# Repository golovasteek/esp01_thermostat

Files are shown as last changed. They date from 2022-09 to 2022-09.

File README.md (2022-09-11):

# Smart Thermostat based on ESP-01 board

ESP-01 Relay module

The software to run on the thermostat to control temperature in the
room with a floor heating.

The target board is ESP-01, but it should be possible to run it on
any ESP8266 board.

The project uses DS18b20 as temperature sensors

GPIO 2 is used to connect with senosor
GPIO 0 is used to control relay, relay is supposed to be active low.

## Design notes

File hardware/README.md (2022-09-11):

# Hardware design of the thermostat

## Tools

The hardware design is made in KiCAD version 5

You can view it on [CADLAB.io](https://cadlab.io/project/25945).

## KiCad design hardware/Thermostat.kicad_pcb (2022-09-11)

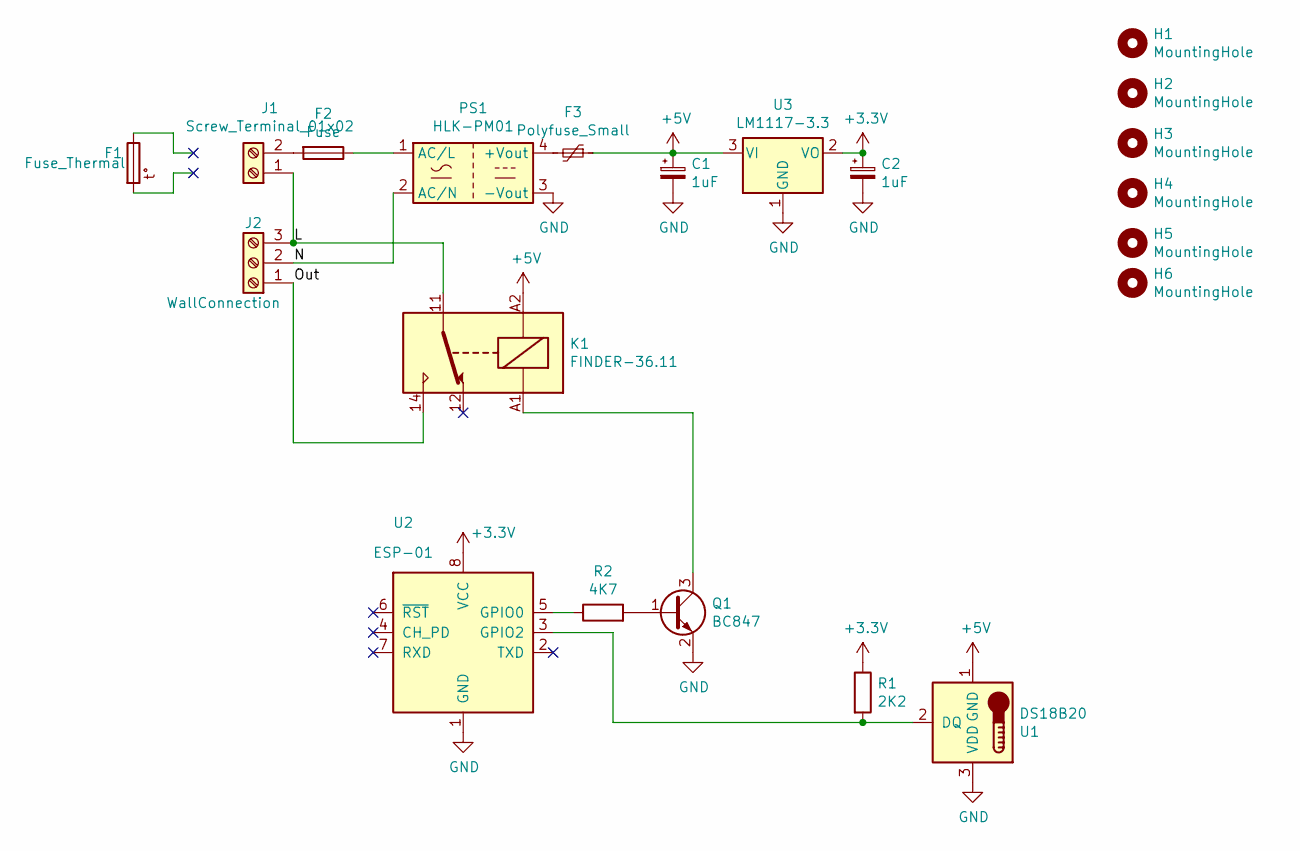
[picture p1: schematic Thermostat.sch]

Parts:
C1, C2: 1uF; CP_EIA-3528-12_Kemet-T_Pad1.50x2.35mm_HandSolder
F1: Fuse_Thermal
F2: Fuse; Fuseholder_Clip_5x20_ESKA
F3: Polyfuse_Small; Fuse_Bourns_MF-RG500
H1, H2: MountingHole; MountingHole_6mm
H3, H4, H5, H6: MountingHole; MountingHole_3.2mm_M3
J1: Screw_Terminal_01x02; TerminalBlock_RND_205-00232_1x02_P5.08mm_Horizontal
J2: WallConnection; TerminalBlock_RND_205-00233_1x03_P5.08mm_Horizontal
K1: FINDER-36.11; Relay_SPDT_Finder_36.11
PS1: HLK-PM01; Converter_ACDC_HiLink_HLK-PMxx
Q1: BC847; SOT-23
R1: 2K2; R_0805_2012Metric_Pad1.20x1.40mm_HandSolder
R2: 4K7; R_0805_2012Metric_Pad1.20x1.40mm_HandSolder
U1: DS18B20; TO-92_Inline
U2: ESP-01; Samtec_HLE-104-02-xx-DV-TE_2x04_P2.54mm_Horizontal
U3: LM1117-3.3; TO-252-3_TabPin2

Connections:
+3V3: C2.1, R1.1, U2.8 (VCC), U3.2 (VO)
+5V: C1.1, F3.1, K1.A2, U1.1 (GND), U3.3 (VI)
/L: J1.1, J2.3, K1.11
/N: J2.2, PS1.2 (AC/N)
/Out: J2.1, K1.14
GND: C1.2, C2.2, PS1.3 (-Vout), Q1.2 (E), U1.3 (VDD), U2.1 (GND), U3.1 (GND)
unnamed: F2.1, PS1.1 (AC/L)
unnamed: F2.2, J1.2
unnamed: F3.2, PS1.4 (+Vout)
unnamed: K1.A1, Q1.3 (C)
unnamed: Q1.1 (B), R2.2
unnamed: R1.2, U1.2 (DQ), U2.3 (GPIO2)
unnamed: R2.1, U2.5 (GPIO0)

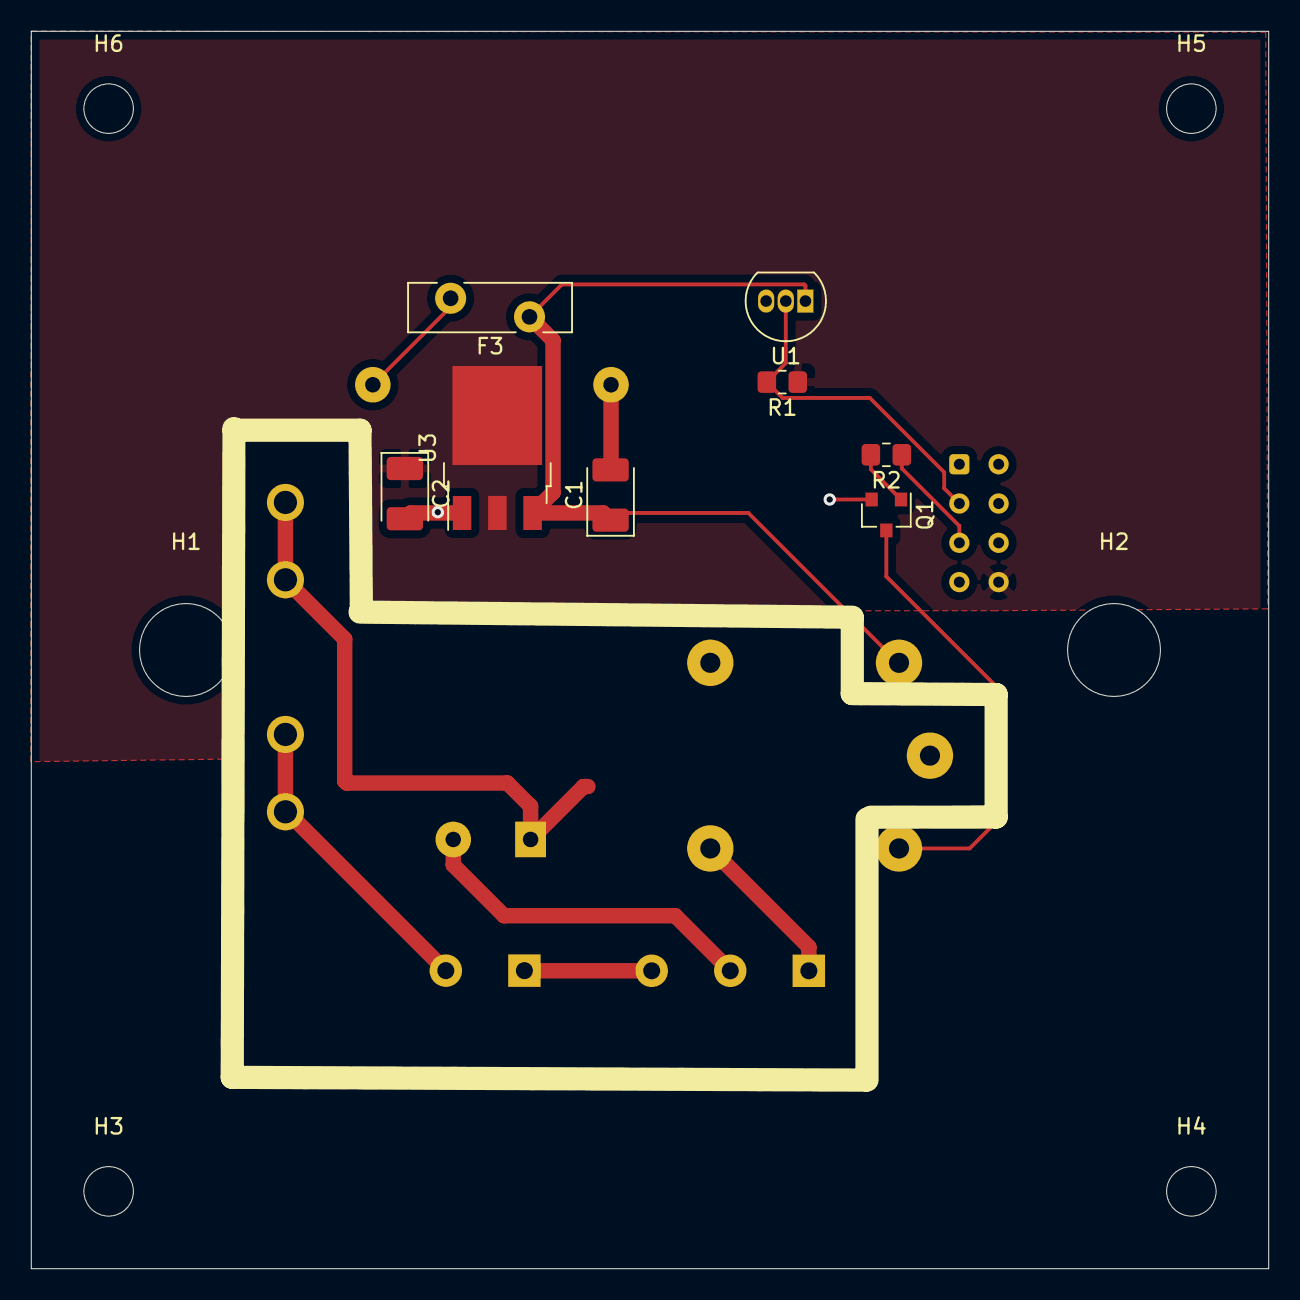
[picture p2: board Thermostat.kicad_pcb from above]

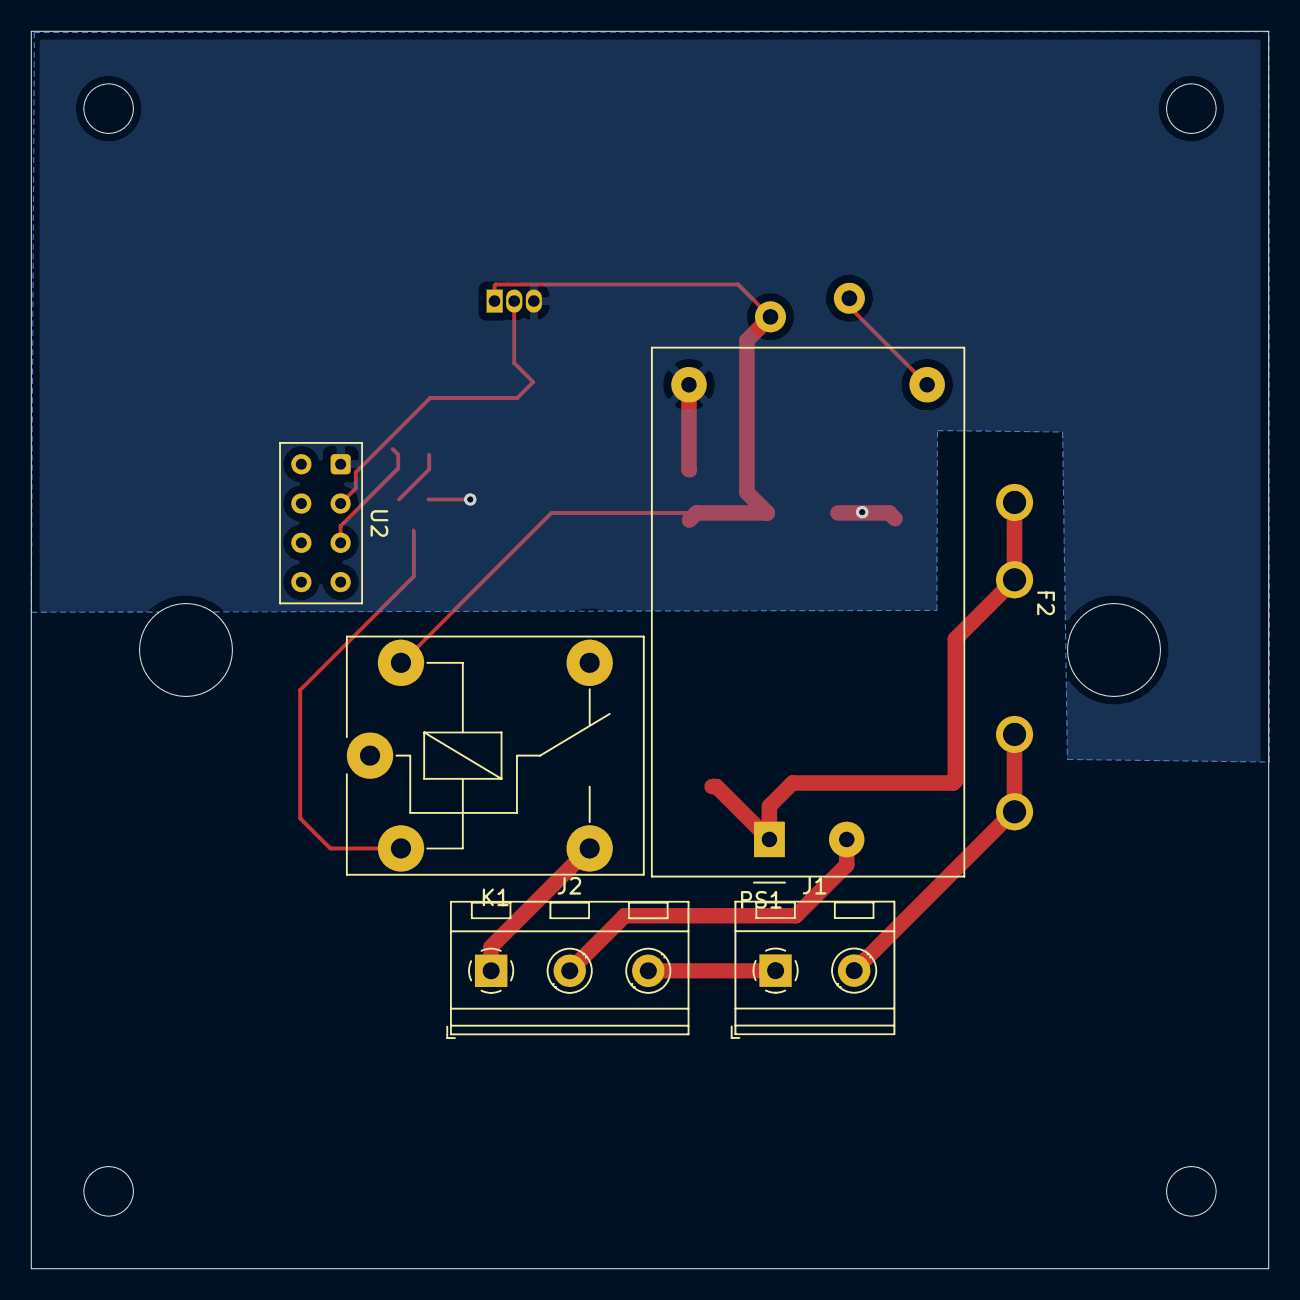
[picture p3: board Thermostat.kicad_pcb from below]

Board: 2 copper layers, 80.0 x 80.0 mm, 20 parts (6 on the bottom side), 13 nets.

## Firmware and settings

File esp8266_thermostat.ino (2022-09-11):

#include <OneWire.h>
#include <DallasTemperature.h>

#include <ArduinoJson.h>
#include <PubSubClient.h>
#include <ESP8266WiFi.h>
#include <WiFiClientSecure.h>
#include <time.h>

#include "temperature_controller.h"
#include "secrets.h"

constexpr int ONE_WIRE_BUS = 2;
constexpr int RELAY_PIN = 0;

constexpr char ssid[] = "fastnet";
constexpr char pass[] = "3Datomic";

float setTemp = 22;
OneWire oneWire(ONE_WIRE_BUS);
DallasTemperature sensors(&oneWire);

BearSSL::X509List caCert(CA_CERT);
BearSSL::X509List clientCert(DEVICE_CERT);
BearSSL::PrivateKey clientKey(DEVICE_KEY);

WiFiClientSecure secureClient;
PubSubClient mqttClient(secureClient);


void messageHandler(char* topic, unsigned char* payload, unsigned int length) {
    Serial.print("Message received: ");
    Serial.print(topic);
    Serial.write(payload, length);
}

time_t now = 0;
const time_t nowish = 1510592825;

void NTPConnect(void)
{
    Serial.print("Setting time using NTP");
    configTime(TIME_ZONE * 3600, 0 * 3600, "pool.ntp.org", "time.nist.gov");
    now = time(nullptr);
    while (now < nowish) {
        delay(500); 
        Serial.print(".");
        now = time(nullptr);
    }
    Serial.println("done!");

    struct tm timeinfo;
    gmtime_r(&now, &timeinfo);
    Serial.print("Current time: ");
    Serial.print(asctime(&timeinfo));
}

void setup_wifi() {
    delay(10);

    Serial.println();
    Serial.print("Connecting to ");
    Serial.println(ssid);

    WiFi.mode(WIFI_STA);
    WiFi.begin(ssid, pass);

    while (WiFi.status() != WL_CONNECTED) {
        delay(500);
        Serial.print(".");
    }

    Serial.println();
    Serial.println("WiFi connected");
    Serial.println("IP address");
    Serial.println(WiFi.localIP());

    delay(1000);

    NTPConnect();

    Serial.println("Setting CA");
    secureClient.setTrustAnchors(&caCert);
    Serial.println("Setting client cert");
    secureClient.setClientRSACert(&clientCert, &clientKey);
    Serial.println("Connecting to host...");
    secureClient.connect(MQTT_HOST, 8883);
    Serial.println("Connecting to broker...");

    mqttClient.setCallback(messageHandler);
    
    Serial.println("Connecting to broker...");
    while (!mqttClient.connect(THING_NAME)) {
        Serial.print(".");
        delay(100);
    }
    Serial.println("Connected to brocker.");
    mqttClient.subscribe("topic_1");
}

void setup() {
    // put your setup code here, to run once:
    Serial.begin(115200);

    setup_wifi();
    sensors.begin();
    int numDevices = sensors.getDeviceCount();
    
    pinMode(RELAY_PIN, OUTPUT);
}

TemperatureController controller(20, 20, SystemClock());

void readTemp() {
    sensors.requestTemperatures();
    float floorTemp = sensors.getTempCByIndex(0);
    float airTemp = sensors.getTempCByIndex(1);

    const auto state = controller.feed(floorTemp, airTemp) ? HIGH : LOW;

    digitalWrite(RELAY_PIN, state);
    
    StaticJsonDocument<200> doc;
    doc["florTemp"] = floorTemp;
    doc["airTemp"] = airTemp;
    char serializedJson[200];
    serializeJson(doc, serializedJson);
    Serial.println(serializedJson);
    mqttClient.publish("topic_2", serializedJson);
}

void loop() {
    // put your main code here, to run repeatedly:
    readTemp();

    while (!mqttClient.connected()) {
        Serial.print("Lost connection to broker, reconnecting");
        if (mqttClient.connect(THING_NAME)) {
            mqttClient.subscribe("topic_1");
        }
    }

    mqttClient.loop();
    delay(1000);
}
